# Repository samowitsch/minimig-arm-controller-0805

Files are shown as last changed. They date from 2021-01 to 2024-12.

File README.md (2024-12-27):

# Minimig-ARM-Controller-0805

Rebuild Minimig ARM Controller board using 0805 SMD components.

> ⚠️ IMPORTANT NOTICE! It seems that only the first rev 1 of my Minimig controller is working! See issue #1

## Preface

Thanks to [Dennis van Weeren](https://en.wikipedia.org/wiki/Minimig), Jakub Bednarski and all contributors for the great [Minimig](https://en.wikipedia.org/wiki/Minimig) project! 
_"Never give up, never surrender!"_ **;o)**

## Disclaimer

> Use/build this project/pcb at your own risk. I am a hobbyist and not an professional 
> electrician or pcb designer and not responsive for any damage to your Minimig.
> 
> By the way my version is not as smart and elegant like the original, i am just using 
> 4 layers instead of two ;o)

## Introduction

Me as a late starter to the Minimig project late 2020 wants to build a [Minimig](https://en.wikipedia.org/wiki/Minimig) to get again the Amiga feeling i 
had a couple of years ago where i owned the most models of the [Amiga](https://en.wikipedia.org/wiki/Amiga) family.

First i tried to solder the [ARM controller board](https://www.amigawiki.org/doku.php?id=de:expansion:storage:minimig_arm_controller) needed for the [Minimig](https://en.wikipedia.org/wiki/Minimig). I ment i was good in soldering but screwed up ;o)
Because of this defeat i decided to make a board using 0805 SMD components for easy hand soldering. And my eyes are also not the very best at all ;-)

## What is included in this repository?

* KiCad files
* Gerber files
* [Firmware files](/firmware/Readme.md)

## BOM

This rebuild pcb uses the same designators as the existing ARM controller.
To buy the parts for this board you can use the existing [a1k.org parts list](resources/minimig_arm_v11fix_bestueckung.pdf).
But instead of 0603 components you can use the larger 0805 smd components.

## How to flash the ARM Controller firmware

The needed firmware [you can find here](https://www.a1k.org/forum/index.php?threads/39601/) (requires registration) or in [this repository](/firmware/Readme.md).

### Flash standalone

1. Connect the TEST header pins with a jumper. Then power up the board with 3.3 V connected to the 
   DC pins (double check correct orientation!) for round about 7 - 10 seconds (see picture below). Shutdown the power again. 
   Remove the jumper from TEST header pins. The Atmel AT91SAM7S256 MCU should be now in usb programming mode.

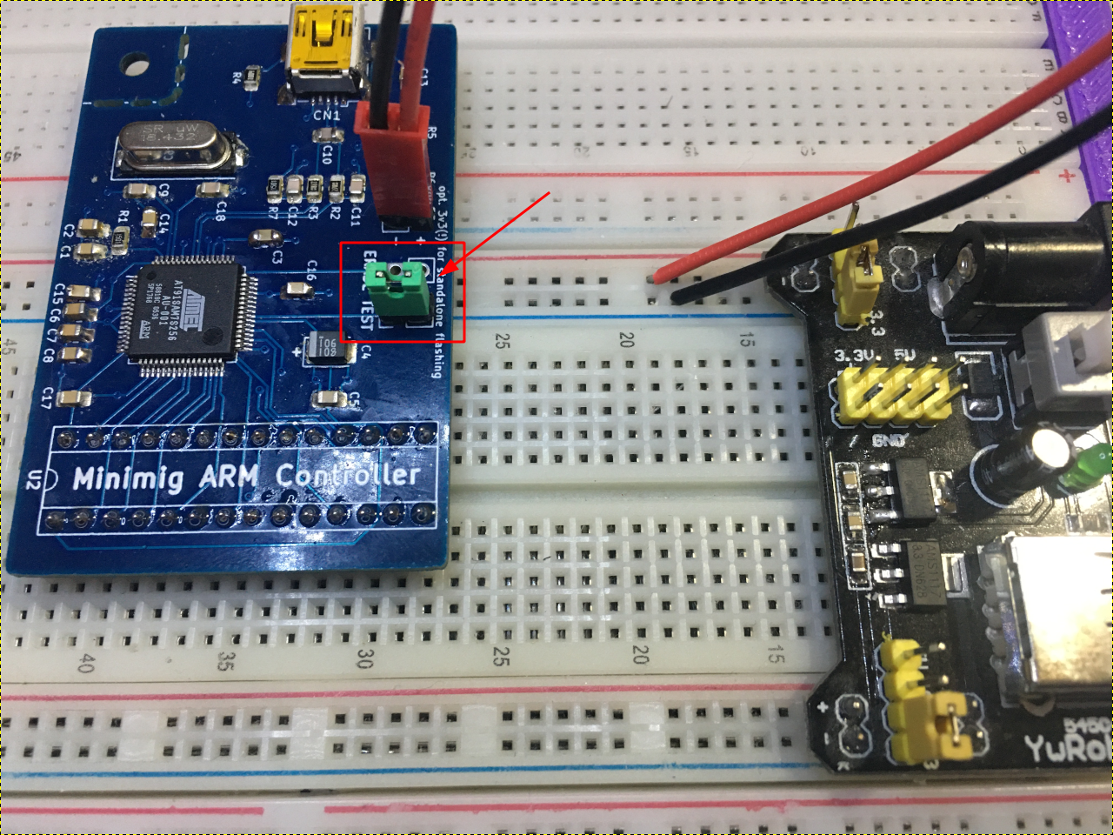
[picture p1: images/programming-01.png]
programming-01


2. Now connect the ARM controller with the USB cable to your pc. And power up the board again.

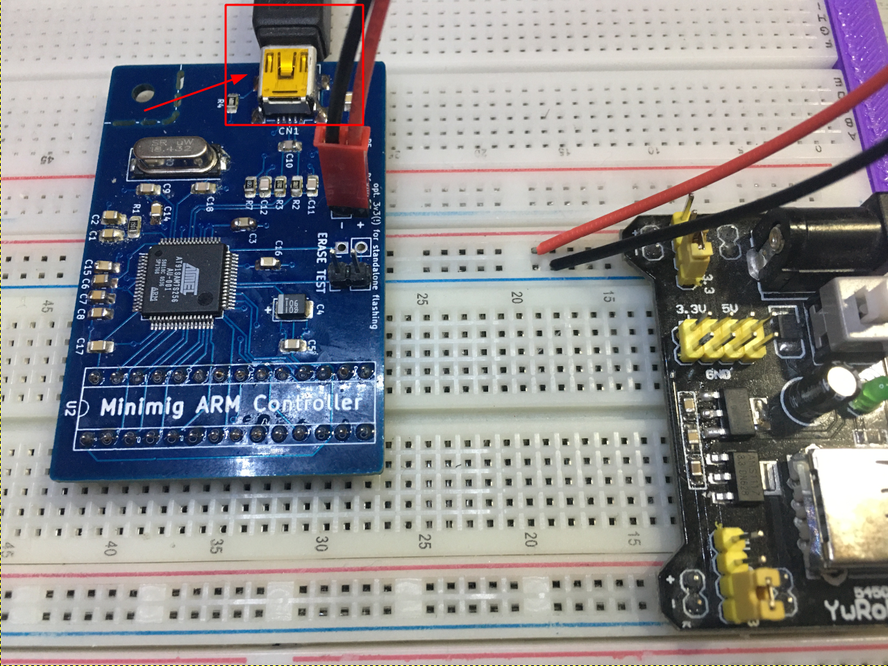
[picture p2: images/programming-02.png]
programming-02


3. For example under Ubuntu you should see now a usb device **/dev/ttyACM0**. For 
   Ubuntu you need the [SAM-BA CDC 2.18](https://www.microchip.com/en-us/development-tool/SAM-BA-In-system-Programmer) ([Download](https://ww1.microchip.com/downloads/en/DeviceDoc/SAM-BA+v2.18+for+Linux.zip)) utility (maybe a newer version is working too).

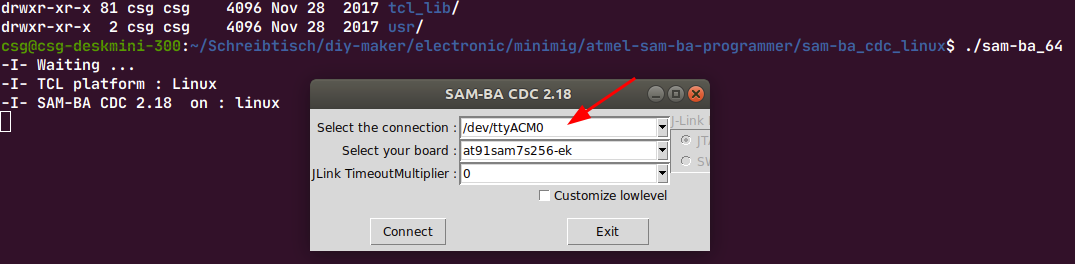
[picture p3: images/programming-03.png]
programming-03


4. When connected choose the bin firmware file and press "Send File".

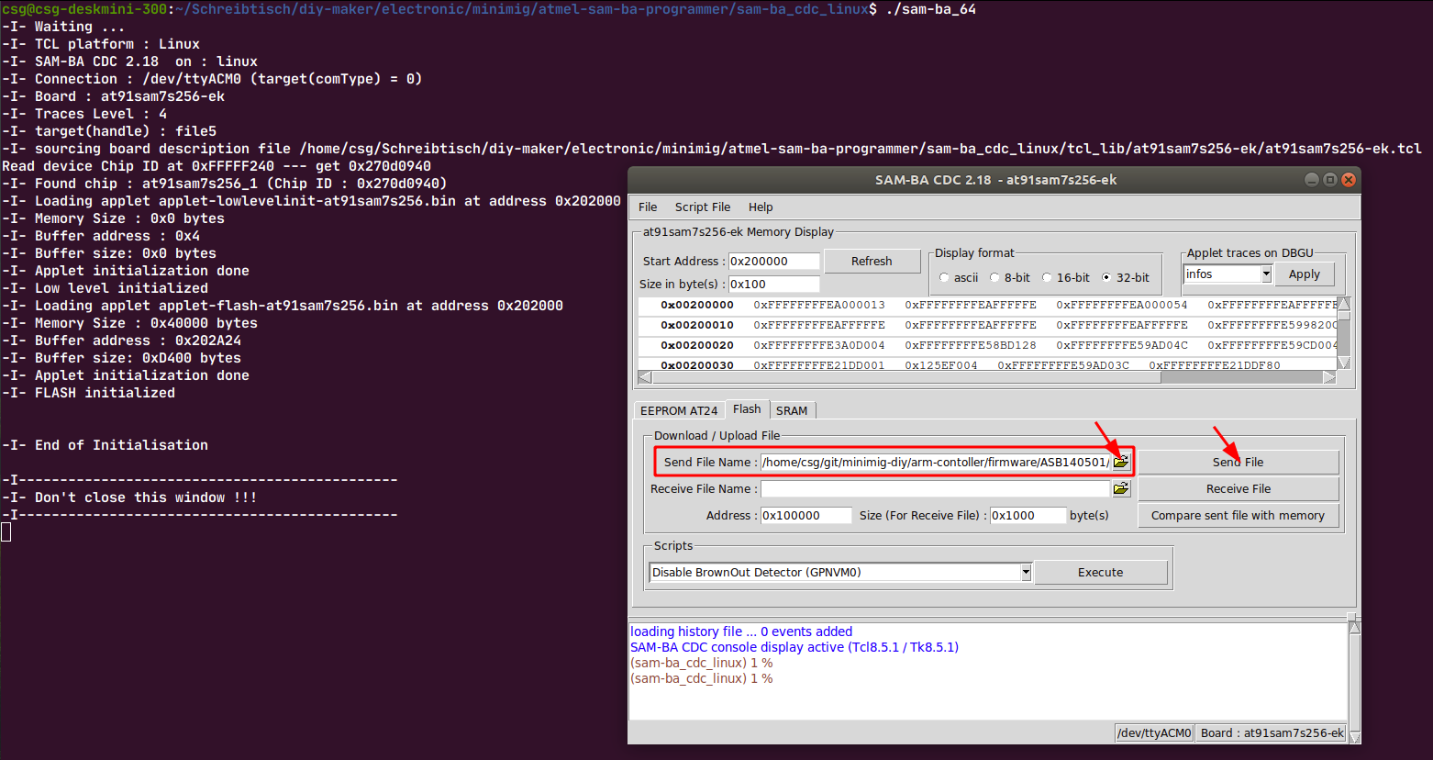
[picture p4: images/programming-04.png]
programming-04


5. In next dialoges for unlock/lock regions you can press "Ja"/"Yes" two times.

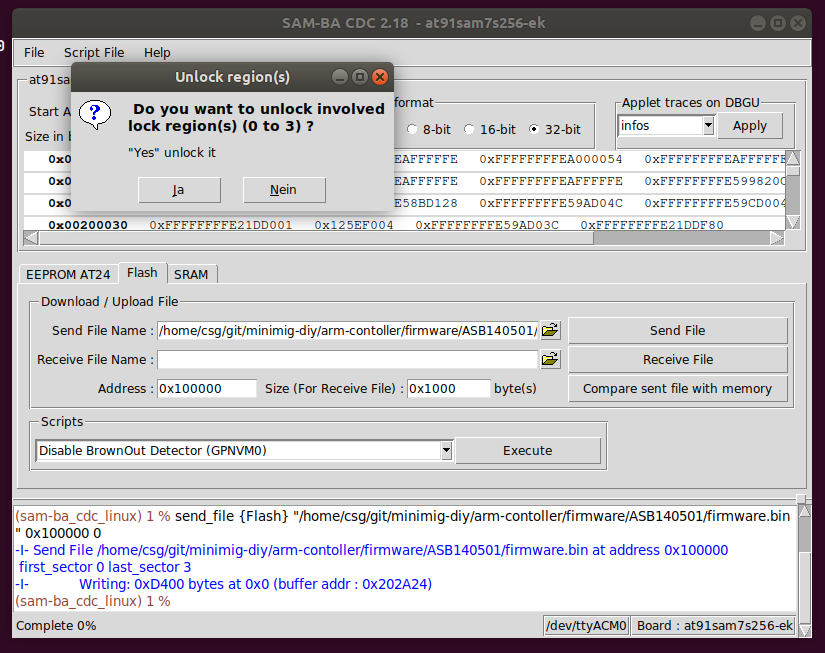
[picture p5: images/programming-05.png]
programming-05

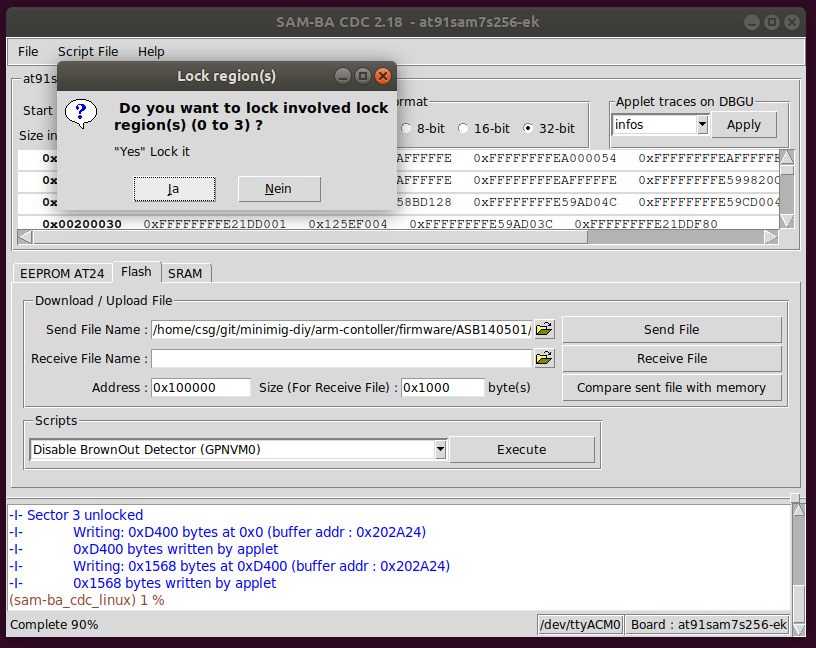
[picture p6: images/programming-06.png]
programming-06


6. At the end you can verify if the flashing process where 
   successfully on pressing "Compare sent file with memory"

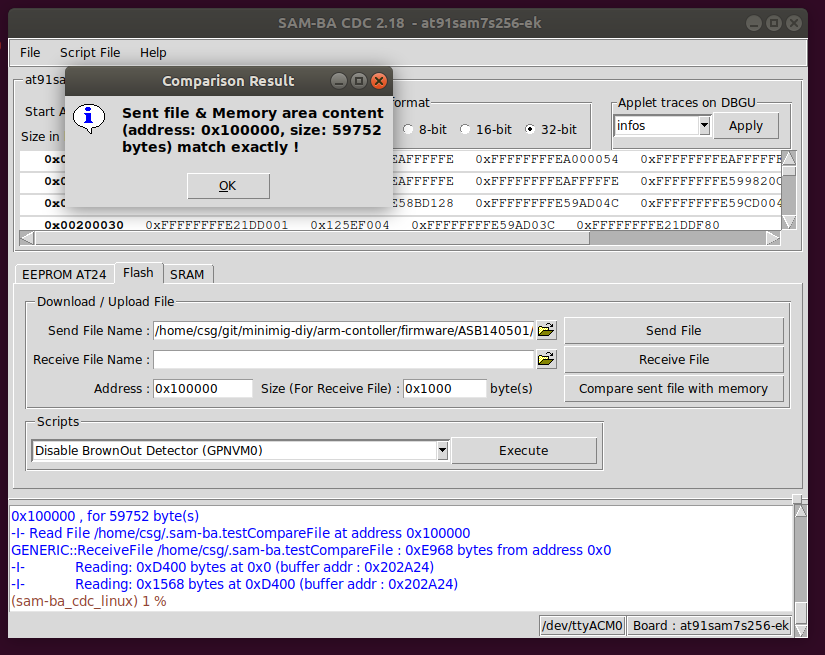
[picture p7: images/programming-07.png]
programming-07


### Flash connected to Minimig

Should work in the same way as described above with the difference that the 
board is connected to the Minimig and get its power from there.

## Mounted ARM controller

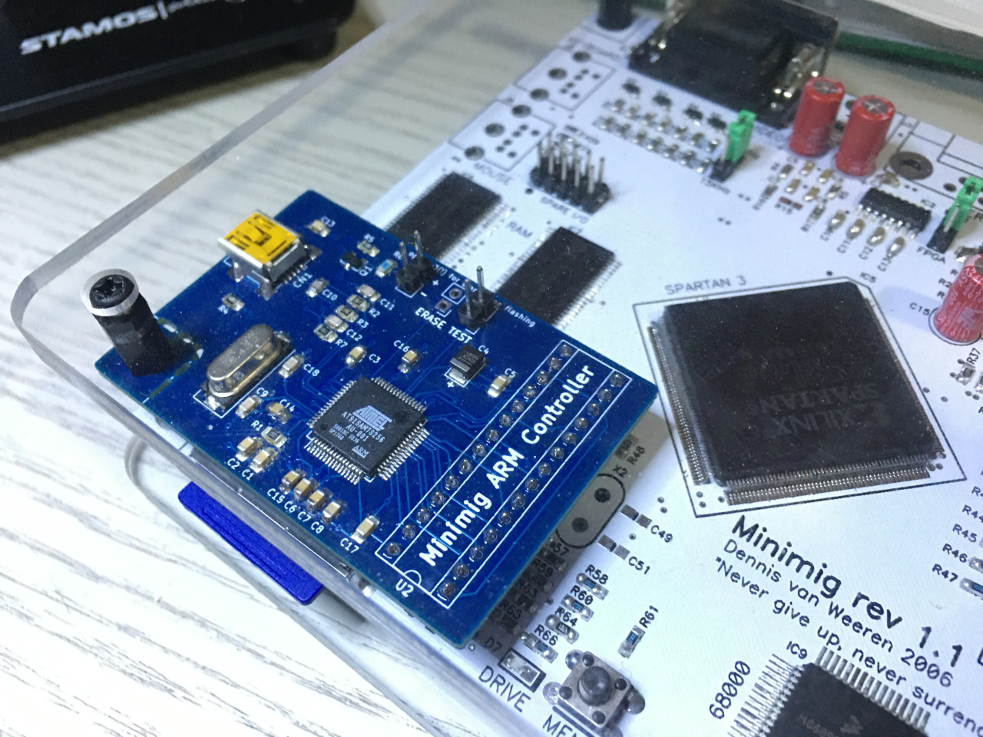
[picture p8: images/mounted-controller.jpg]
mounted-controller


## Running Minimig v1.1 with my version

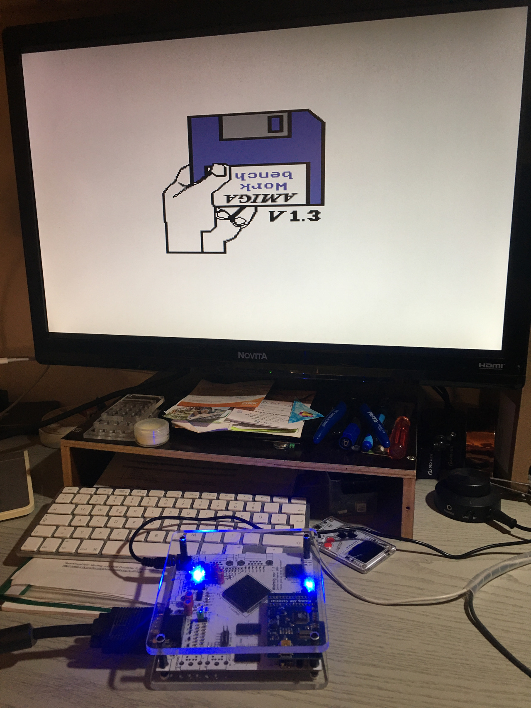
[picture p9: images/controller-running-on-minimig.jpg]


## PCB Layers

Layer Nr | Comment
--- | ---
1 | Signal
2 | +1V8 plane VDDCORE
3 | +3V3 plane VDDIN
4 | GND plane/Signal

## Comparison between versions

0805 rev1.0.3 | 0805 rev1.0.2 | 0805 rev1 | original 0603 version
--- | --- | --- | ---
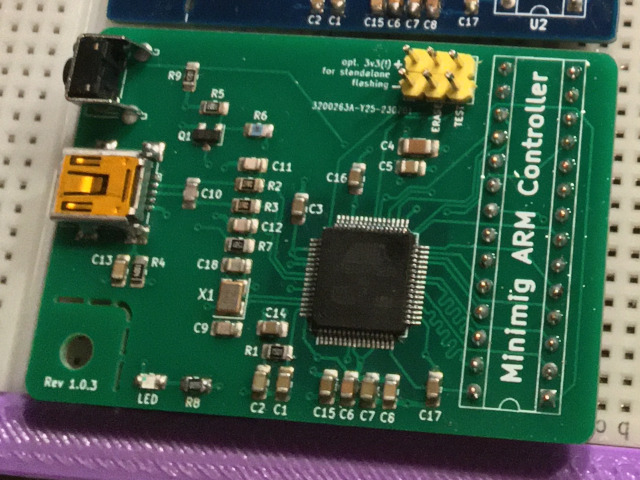
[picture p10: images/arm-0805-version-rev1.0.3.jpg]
arm-0805-version
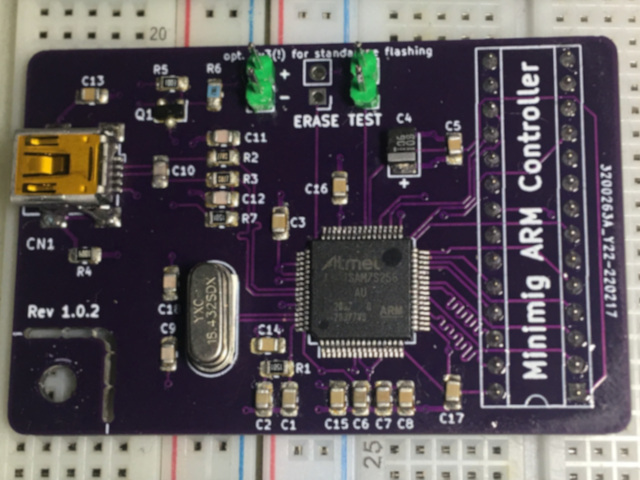
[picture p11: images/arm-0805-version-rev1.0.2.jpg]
arm-0805-version
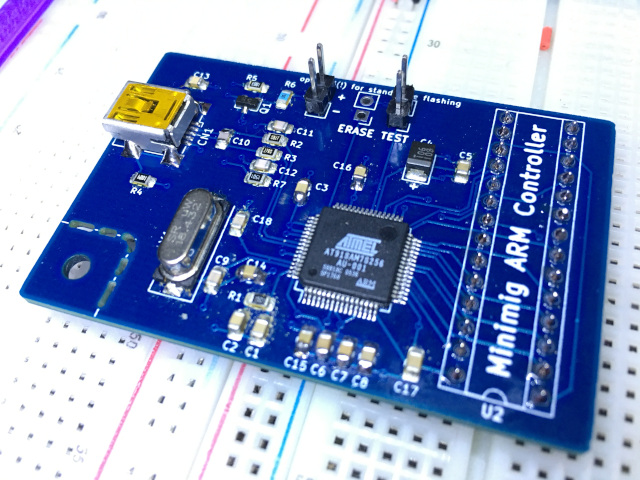
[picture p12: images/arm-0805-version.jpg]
arm-0805-version
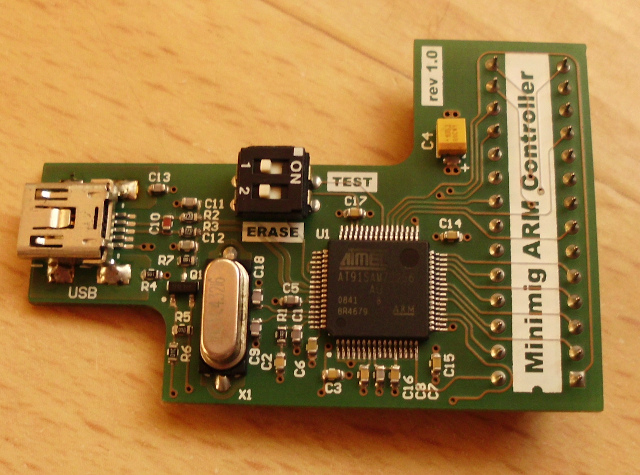
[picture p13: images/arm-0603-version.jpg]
arm-0603-version
 |  |                | 
no stable | not stable | stable(?) |
changes: reset button, power led, smd resonator | changes: dont know anymore ;o) |  | What a beauty of a pcb design of Jakub!
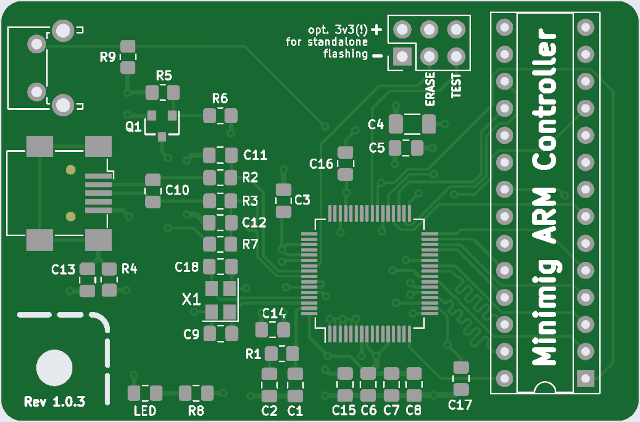
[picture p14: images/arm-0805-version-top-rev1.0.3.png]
arm-0805-version-top
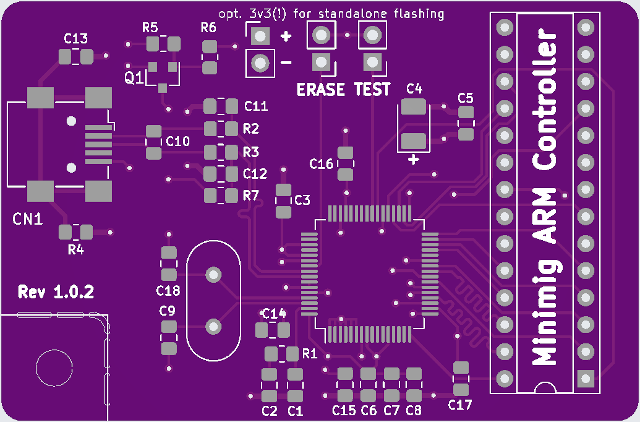
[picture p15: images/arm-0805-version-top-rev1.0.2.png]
arm-0805-version-top
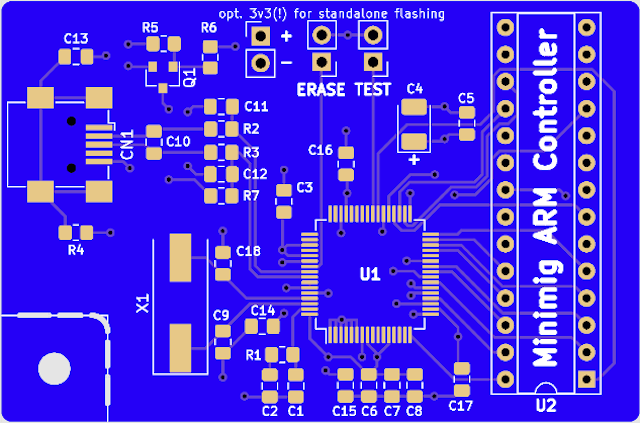
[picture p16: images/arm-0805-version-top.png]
arm-0805-version-top
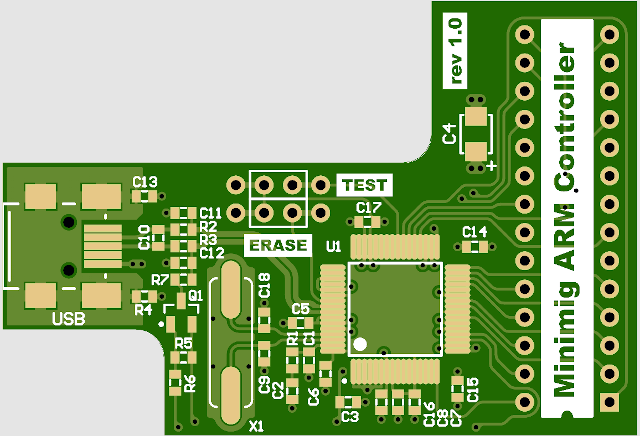
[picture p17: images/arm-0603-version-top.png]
arm-0603-version-top
 |  |  | 
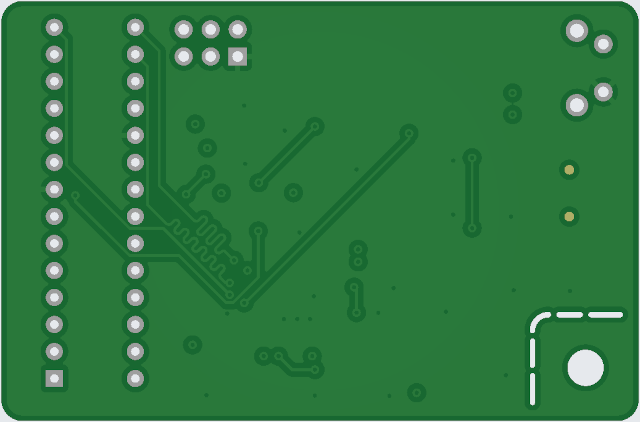
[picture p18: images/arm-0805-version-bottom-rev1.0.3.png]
arm-0805-version-bottom
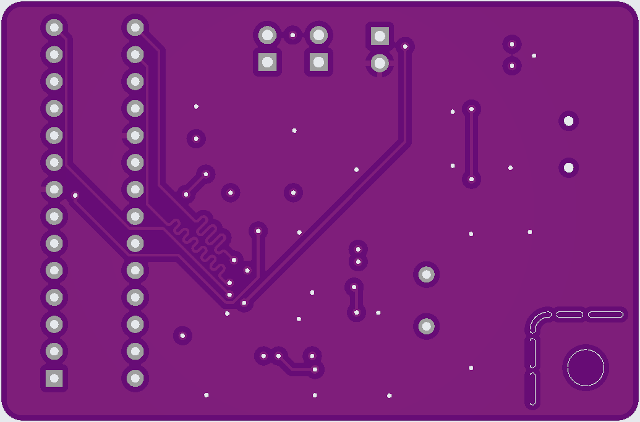
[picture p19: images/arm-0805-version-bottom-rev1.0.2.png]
arm-0805-version-bottom
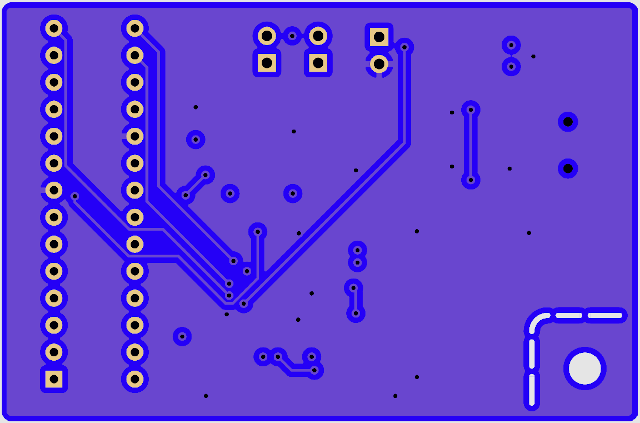
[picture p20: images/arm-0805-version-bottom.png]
arm-0805-version-bottom
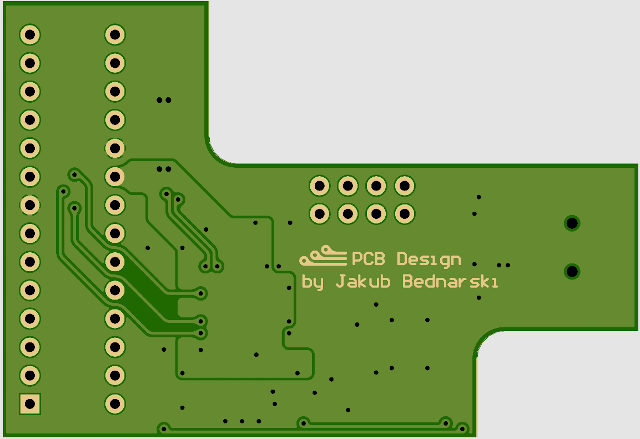
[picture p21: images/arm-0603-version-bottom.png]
arm-0603-version-bottom
 |  |  | 

## Resources and links

* [Original Minimig page](https://www.techtravels.org/wp-content/uploads/pefiles/minimig/weeren001/minimig.html)
* [Minimig on a1k.org](https://www.a1k.org/forum/index.php?forums/53/)
* [Minimig on amigawiki.org](https://www.amigawiki.org/doku.php?id=de:models:minimig)
* [Minimig on Wikipedia](https://en.wikipedia.org/wiki/Minimig)
* [Minimig on Illuwatar Design](http://www.illuwatar.se/)
* [Make: Poor man's Minimig ARM Controller](https://sweetlilmre.blogspot.com/2013/05/make-poor-mans-minimig-arm-controller.html)
* [An FPPGA based Amiga – The Minimig](https://theretrohacker.com/2022/12/20/an-fppga-based-amiga-the-minimig/)
* [cristianoag/minimig](https://github.com/cristianoag/minimig)
* [wiretap-retro/MigStorm-ITX](https://github.com/wiretap-retro/MigStorm-ITX)
* [minimig.ca](https://www.minimig.ca/index.php/software/)
* [0805 Minimig Arm Controller on MigStorm ITX](https://youtu.be/l10HLR_F88E?si=PKMIdRAqAoQ9IPDd&t=572)

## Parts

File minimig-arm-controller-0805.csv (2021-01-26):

Reference | Quantity | Value | Footprint | Datasheet
C10 | 1 | 33p | Capacitor_SMD:C_0805_2012Metric_Pad1.18x1.45mm_HandSolder | ~
C11 C12 | 2 | 15p | Capacitor_SMD:C_0805_2012Metric_Pad1.18x1.45mm_HandSolder | ~
C1 C5 C8 C13 | 4 | 1n | Capacitor_SMD:C_0805_2012Metric_Pad1.18x1.45mm_HandSolder | ~
C9 C18 | 2 | 10p | Capacitor_SMD:C_0805_2012Metric_Pad1.18x1.45mm_HandSolder | ~
C2 | 1 | 10n | Capacitor_SMD:C_0805_2012Metric_Pad1.18x1.45mm_HandSolder | ~
C3 C14 C15 C16 C17 | 5 | 100n | Capacitor_SMD:C_0805_2012Metric_Pad1.18x1.45mm_HandSolder | ~
C4 | 1 | 10u/16V | Capacitor_Tantalum_SMD:CP_EIA-3528-21_Kemet-B_Pad1.50x2.35mm_HandSolder | ~
C6 C7 | 2 | 1u | Capacitor_SMD:C_0805_2012Metric_Pad1.18x1.45mm_HandSolder | ~
CN1 | 1 | USB_B_Mini | Connector_USB:USB_Mini-B_Wuerth_65100516121_Horizontal | ~
JP1 J1 JP2 | 3 | Conn_01x02_Male | Connector_PinHeader_2.54mm:PinHeader_1x02_P2.54mm_Vertical | ~
Q1 | 1 | BC807 | Package_TO_SOT_SMD:SOT-23 | https://www.onsemi.com/pub/Collateral/BC808-D.pdf
R2 R3 | 2 | 27R | Resistor_SMD:R_0805_2012Metric_Pad1.20x1.40mm_HandSolder | ~
R4 | 1 | 1M | Resistor_SMD:R_0805_2012Metric_Pad1.20x1.40mm_HandSolder | ~
R5 | 1 | 100K | Resistor_SMD:R_0805_2012Metric_Pad1.20x1.40mm_HandSolder | ~
R6 | 1 | 10K | Resistor_SMD:R_0805_2012Metric_Pad1.20x1.40mm_HandSolder | ~
R1 R7 | 2 | 1K5 | Resistor_SMD:R_0805_2012Metric_Pad1.20x1.40mm_HandSolder | ~
U1 | 1 | AT91SAM7S256 | Package_QFP:LQFP-64_10x10mm_P0.5mm
U2 | 1 | PIC_PIN_HEADER | Package_DIP:DIP-28_W7.62mm_Socket
X1 | 1 | 18.342MHz | Crystal:Crystal_SMD_HC49-SD | ~

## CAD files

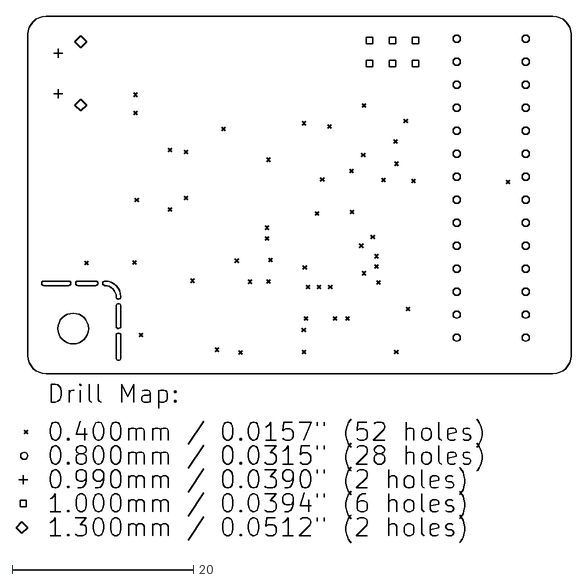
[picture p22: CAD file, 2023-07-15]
gerber/minimig-arm-controller-0805-PTH-drl_map.dxf
61.3 x 58.2

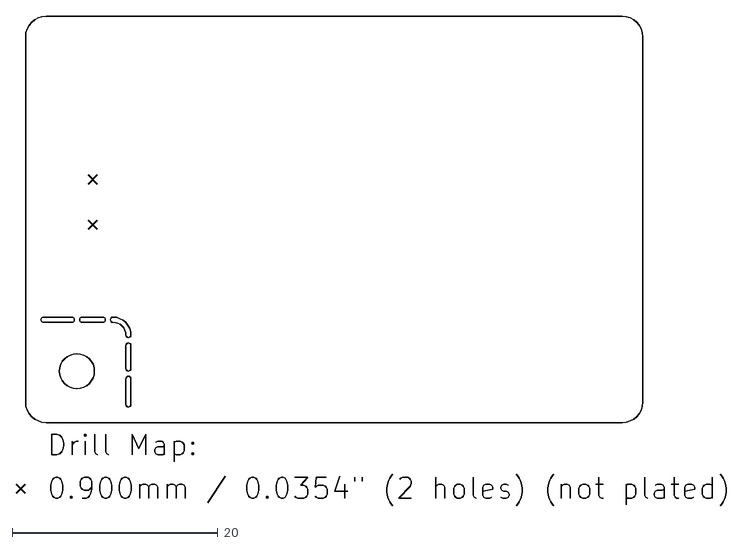
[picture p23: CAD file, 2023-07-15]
gerber/minimig-arm-controller-0805-NPTH-drl_map.dxf
69.0 x 47.6

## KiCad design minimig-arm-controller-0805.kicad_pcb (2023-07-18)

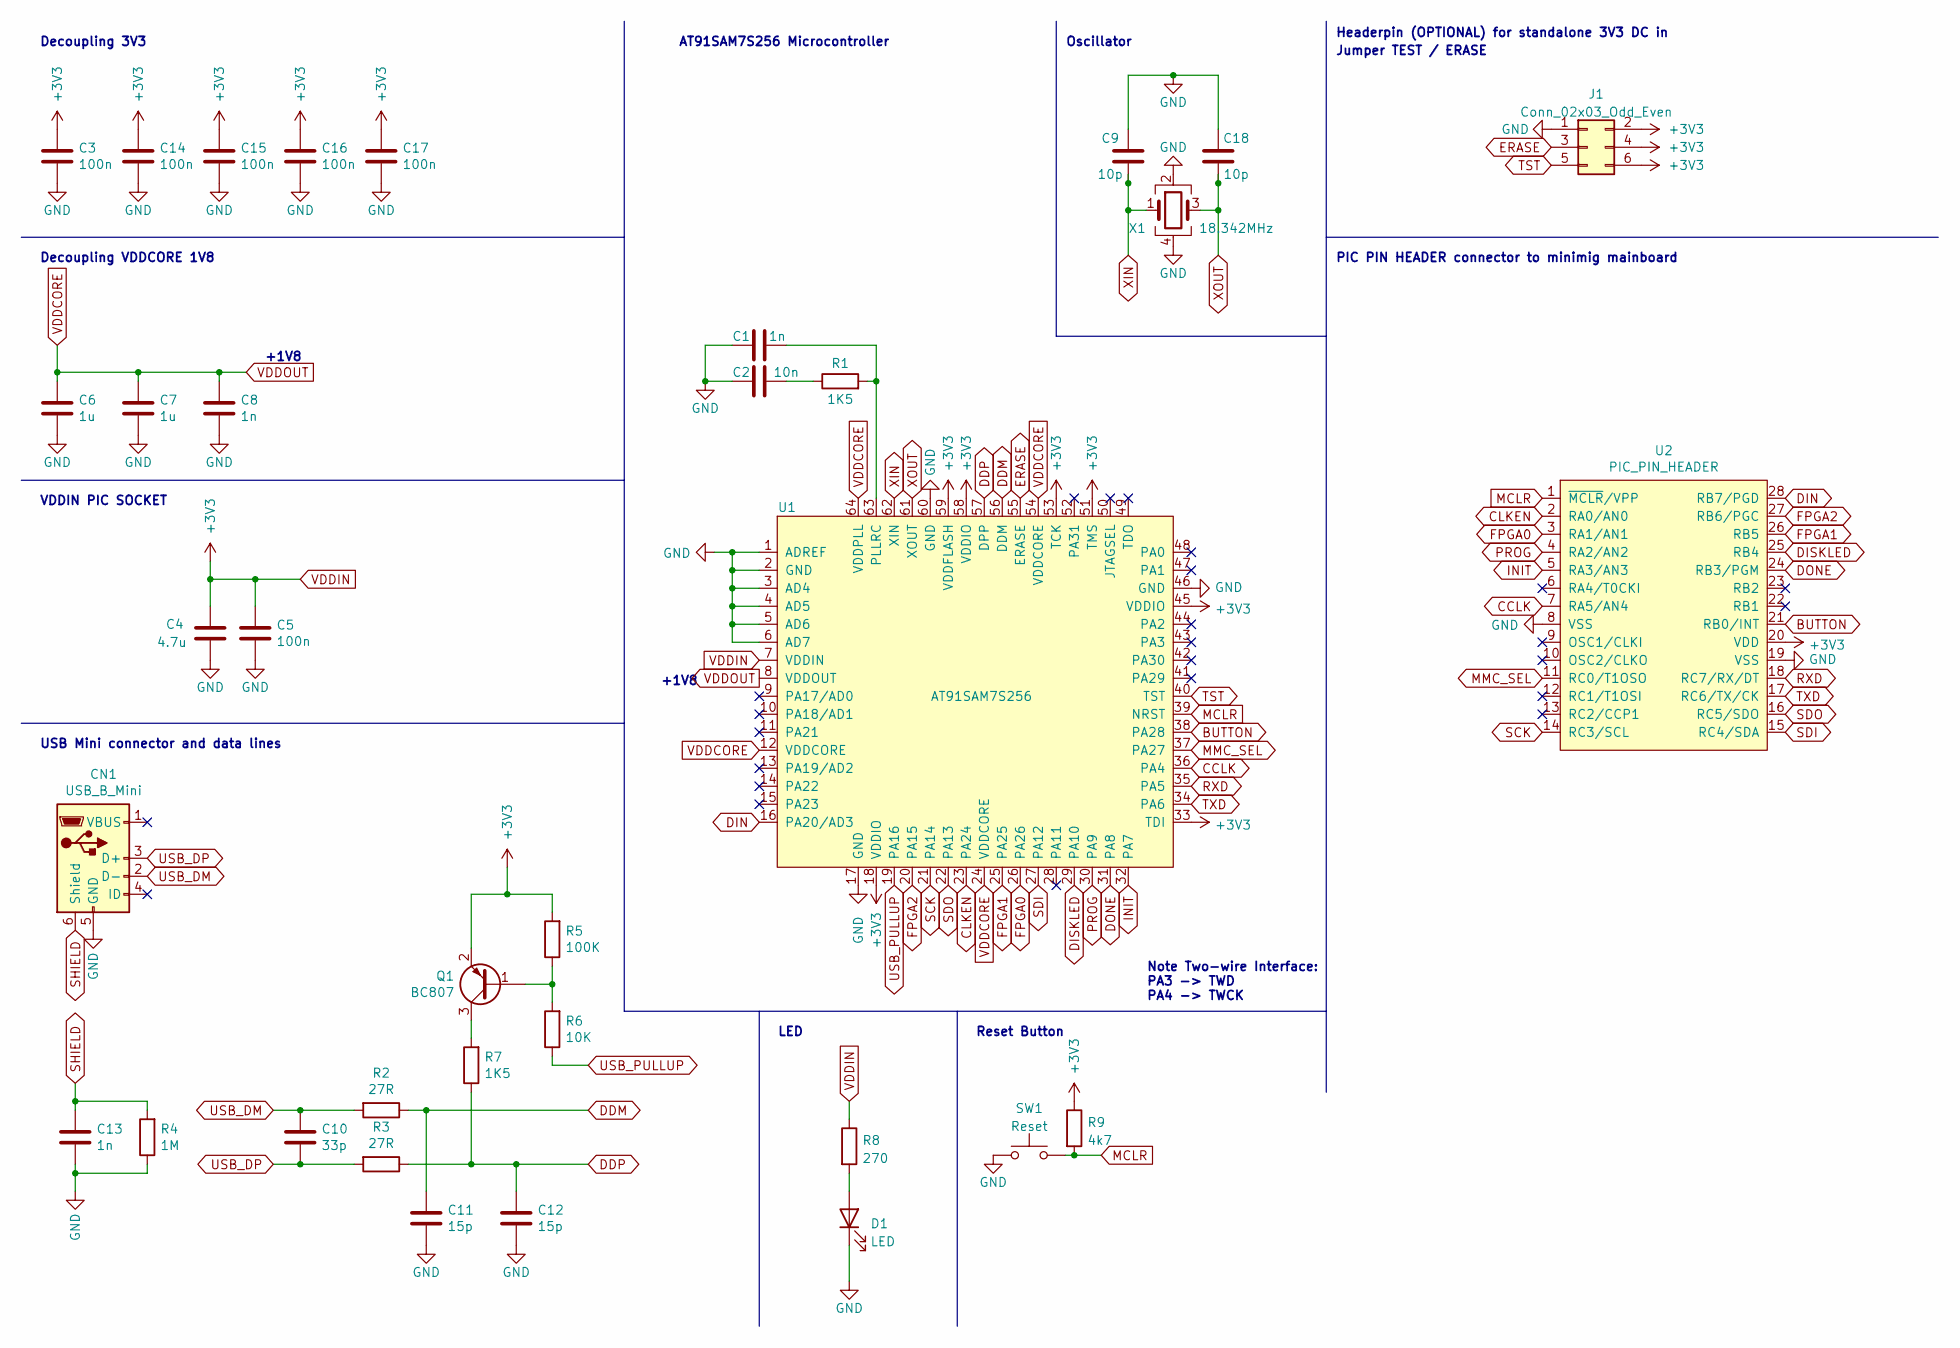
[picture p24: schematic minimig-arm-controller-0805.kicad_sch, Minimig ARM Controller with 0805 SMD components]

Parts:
C1, C8, C13: 1n; C_0805_2012Metric_Pad1.18x1.45mm_HandSolder
C2: 10n; C_0805_2012Metric_Pad1.18x1.45mm_HandSolder
C3, C5, C14, C15, C16, C17: 100n; C_0805_2012Metric_Pad1.18x1.45mm_HandSolder
C4: 4.7u; C_1206_3216Metric_Pad1.33x1.80mm_HandSolder
C6, C7: 1u; C_0805_2012Metric_Pad1.18x1.45mm_HandSolder
C9, C18: 10p; C_0805_2012Metric_Pad1.18x1.45mm_HandSolder
C10: 33p; C_0805_2012Metric_Pad1.18x1.45mm_HandSolder
C11, C12: 15p; C_0805_2012Metric_Pad1.18x1.45mm_HandSolder
CN1: USB_B_Mini; USB_Mini-B_Wuerth_65100516121_Horizontal
D1: LED; C_0805_2012Metric_Pad1.18x1.45mm_HandSolder
J1: Conn_02x03_Odd_Even; PinHeader_2x03_P2.54mm_Vertical
Q1: BC807; SOT-23
R1, R7: 1K5; R_0805_2012Metric_Pad1.20x1.40mm_HandSolder
R2, R3: 27R; R_0805_2012Metric_Pad1.20x1.40mm_HandSolder
R4: 1M; R_0805_2012Metric_Pad1.20x1.40mm_HandSolder
R5: 100K; R_0805_2012Metric_Pad1.20x1.40mm_HandSolder
R6: 10K; R_0805_2012Metric_Pad1.20x1.40mm_HandSolder
R8: 270; C_0805_2012Metric_Pad1.18x1.45mm_HandSolder
R9: 4k7; R_0805_2012Metric_Pad1.20x1.40mm_HandSolder
SW1: Reset; SW_Tactile_SPST_Angled_PTS645Vx39-2LFS
U1: AT91SAM7S256; LQFP-64_10x10mm_P0.5mm
U2: PIC_PIN_HEADER; DIP-28_W7.62mm_Socket
X1: 18.342MHz; Crystal_SMD_3225-4Pin_3.2x2.5mm

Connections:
BUTTON: U1.38 (PA28), U2.21 (RB0/INT)
CCLK: U1.36 (PA4), U2.7 (RA5/AN4)
CLKEN: U1.23 (PA24), U2.2 (RA0/AN0)
DDM: C11.1, R2.1, U1.56 (DDM)
DDP: C12.1, R3.1, R7.1, U1.57 (DPP)
DIN: U1.16 (PA20/AD3), U2.28 (RB7/PGD)
DISKLED: U1.29 (PA10), U2.25 (RB4)
DONE: U1.31 (PA8), U2.24 (RB3/PGM)
ERASE: J1.3, U1.55 (ERASE)
FPGA0: U1.26 (PA26), U2.3 (RA1/AN1)
FPGA1: U1.25 (PA25), U2.26 (RB5)
FPGA2: U1.20 (PA15), U2.27 (RB6/PGC)
GND: C1.2, C2.2, C3.2, C4.2, C5.2, C6.2, C7.2, C8.2, C9.2, C11.2, C12.2, C13.2, C14.2, C15.2, C16.2, C17.2, C18.2, CN1.5 (GND), D1.1 (K), J1.1, R4.1, SW1.1, U1.1 (ADREF), U1.2 (GND), U1.3 (AD4), U1.4 (AD5), U1.5 (AD6), U1.6 (AD7), U1.17 (GND), U1.46 (GND), U1.60 (GND), U2.8 (VSS), U2.19 (VSS), X1.2, X1.4
INIT: U1.32 (PA7), U2.5 (RA3/AN3)
MCLR: R9.2, SW1.2, U1.39 (NRST), U2.1 (~MCLR/VPP)
MMC_SEL: U1.37 (PA27), U2.11 (RC0/T1OSO)
unnamed: C1.1, R1.2, U1.63 (PLLRC)
unnamed: C2.1, R1.1
unnamed: D1.2 (A), R8.2
unnamed: Q1.1 (B), R5.1, R6.2
unnamed: Q1.3 (C), R7.2
PROG: U1.30 (PA9), U2.4 (RA2/AN2)
RXD: U1.35 (PA5), U2.18 (RC7/RX/DT)
SCK: U1.21 (PA14), U2.14 (RC3/SCL)
SDI: U1.27 (PA12), U2.15 (RC4/SDA)
SDO: U1.22 (PA13), U2.16 (RC5/SDO)
SHIELD: C13.1, CN1.6 (Shield), R4.2
TST: J1.5, U1.40 (TST)
TXD: U1.34 (PA6), U2.17 (RC6/TX/CK)
USB_DM: C10.1, CN1.2 (D-), R2.2
USB_DP: C10.2, CN1.3 (D+), R3.2
USB_PULLUP: R6.1, U1.19 (PA16)
VDDCORE: C6.1, C7.1, C8.1, U1.8 (VDDOUT), U1.12 (VDDCORE), U1.24 (VDDCORE), U1.54 (VDDCORE), U1.64 (VDDPLL)
VDDIN: C3.1, C4.1, C5.1, C14.1, C15.1, C16.1, C17.1, J1.2, J1.4, J1.6, Q1.2 (E), R5.2, R8.1, R9.1, U1.7 (VDDIN), U1.18 (VDDIO), U1.33 (TDI), U1.45 (VDDIO), U1.51 (TMS), U1.53 (TCK), U1.58 (VDDIO), U1.59 (VDDFLASH), U2.20 (VDD)
XIN: C9.1, U1.62 (XIN), X1.1
XOUT: C18.1, U1.61 (XOUT), X1.3

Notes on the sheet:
Decoupling VDDCORE 1V8
LED
USB Mini connector and data lines
Headerpin (OPTIONAL) for standalone 3V3 DC in
VDDIN PIC SOCKET
PIC PIN HEADER connector to minimig mainboard
+1V8
Oscillator
Jumper TEST / ERASE
Decoupling 3V3
Note Two-wire Interface: PA3 -> TWD PA4 -> TWCK
Reset Button
AT91SAM7S256 Microcontroller

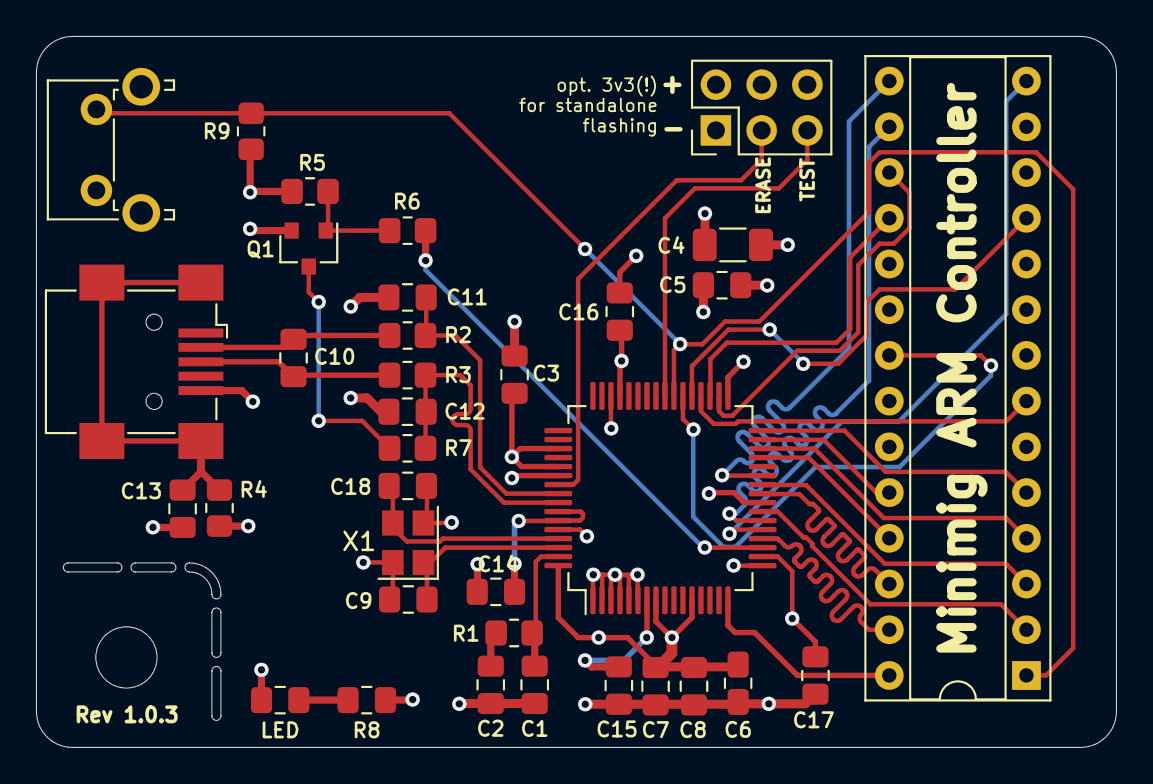
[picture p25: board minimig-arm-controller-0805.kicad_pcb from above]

Board: 4 copper layers, 60.0 x 39.5 mm, 35 parts (0 on the bottom side), 36 nets.

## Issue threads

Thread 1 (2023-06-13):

has anyone done the test?

juanpc2018, 2023-06-13:
since this mod is only  for the original minimig v1.3
https://www.techtravels.org/wp-content/uploads/pefiles/minimig/weeren001/home.html
https://www.minimig.ca/index.php/2021/07/19/minimig-v1-3/

has anyone tested:
Minimig 1.3 + ARM
vs.
New Minimig https://www.minimig.ca/
vs.
MIST https://lotharek.pl/productdetail.php?id=45
vs.
MISTer ?

samowitsch, 2023-06-19:
That's not really a issue. Rather a performance question for a amiga retro forum.
Personally, i only own a Minimig V1.1 with ARM controller and have no comparison to other solutions.

Closed 2023-06-19.

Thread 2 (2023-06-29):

ℹ️ Arm controller not working properly ? 😤

samowitsch, 2023-06-29:
Brief history. Back in 2020, at the beginning of soldering my miming, I failed to solder Jacub's 0603 arm controller.
This is the reason why this repo exists. It is lets say a replica with 0805 components that i made.

I am just soldering again some Arm Controllers for the Minimig and this is driving me nuts. All new soldered Arm controllers are not working propery. Each Rev i made. Only the first two blue rev 1 versions that i made in the past are working.

And all the successors in blue (even the "old" blue rev1 pcb too), green and purple do not work reliably.
Minimig is starting up and then fails randomly with a bluescreen. The latest point is trying to upload the kickstart into memory.

I don't know exactly what the problem is. I am not sure. Maybe i have an issue on the pcb or even faulty components or china clones of the Atmel AT91SAM7S256 MCU? Who knows...

The blue at the bottom is working.
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

samowitsch, 2023-07-15:
The rev1.0.3 has the same behaviour a the others before 🥴

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

It stucks on the blue bootscreen. Mostly it hangs when he tries to upload the kickstart into ram.

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
The output has some jitter (not visible on photo).

Maybe there is a power issue. Or my bad pcb layout is the reason. Or in worst case with the mcu itself. My running versions are  all labeled with **AU-001** ? 🤔

samowitsch, 2025-01-01:
Surprisingly i found a YT video with a working rev 1.0.2 of my minimig arm controller pcb 🤗
Then some components that i have used is causing my problems 😡

https://youtu.be/l10HLR_F88E?si=VD0iGX84BHG4OUzv&t=526

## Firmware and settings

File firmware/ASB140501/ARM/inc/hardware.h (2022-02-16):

#define MCLK 48000000
#define FWS 1 // Flash wait states

#define DISKLED    AT91C_PIO_PA10
#define MMC_CLKEN  AT91C_PIO_PA24
#define MMC_SEL    AT91C_PIO_PA27
#define DIN AT91C_PIO_PA20
#define CCLK AT91C_PIO_PA4
#define PROG_B AT91C_PIO_PA9
#define INIT_B AT91C_PIO_PA7
#define DONE AT91C_PIO_PA8
#define FPGA0 AT91C_PIO_PA26
#define FPGA1 AT91C_PIO_PA25
#define FPGA2 AT91C_PIO_PA15
#define BUTTON AT91C_PIO_PA28

#define DISKLED_ON *AT91C_PIOA_SODR = DISKLED;
#define DISKLED_OFF *AT91C_PIOA_CODR = DISKLED;
// #define RAMFUNC   __attribute__ ((section(".ramsection")))
#define RAMFUNC __attribute__ ((section (".text.fastcode")))
void init_hardware(void);
void USART_Init(unsigned long baudrate);
void USART_Write(unsigned char c);
void USART_Putc(void* p, char c);
RAMFUNC void SPI_Init(void);
RAMFUNC unsigned char SPI(unsigned char outByte);
RAMFUNC void SPI_Wait4XferEnd(void);
RAMFUNC void EnableCard(void);
RAMFUNC void DisableCard(void);
void EnableFpga(void);
void DisableFpga(void);
void EnableOsd(void);
void DisableOsd(void);
unsigned long CheckButton(void);
void Timer_Init(void);
unsigned long GetTimer(unsigned long offset);
unsigned long CheckTimer(unsigned long t);
void WaitTimer(unsigned long time);

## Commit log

2021-01-26 add KiCad project files
    [minimig-arm-controller-0805-B_Cu.gbr, minimig-arm-controller-0805-B_Mask.gbr, minimig-arm-controller-0805-B_Paste.gbr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]
2021-01-27 added original ARM Controller files
2021-02-10 add text info to schematic about TWI(I2C) pins
    [minimig-arm-controller-0805.sch]
2021-05-22 use handsoldering footprint for HC49-SD crystal
    [minimig-arm-controller-0805-B_Cu.gbr, minimig-arm-controller-0805-B_Mask.gbr, minimig-arm-controller-0805-B_Paste.gbr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]
2022-02-16 rev1.0.2: some minor changes. change HC49 to THT
    [minimig-arm-controller-0805-B_Cu.gbr, minimig-arm-controller-0805-B_Mask.gbr, minimig-arm-controller-0805-B_Paste.gbr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]
2022-02-16 remove and gitignore kicad backups
2022-02-17 rev1.0.3 reroute some stuff
    [minimig-arm-controller-0805-B_Cu.gbr, minimig-arm-controller-0805-B_Mask.gbr, minimig-arm-controller-0805-B_Paste.gbr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]
2023-06-23 added warning/notive about later pcb revisions that are not working. Dont know why at the moment ;o(
2023-07-08 add gcc-arm-none-eabi-4_8-2014q1-20140314-linux.tar.bz2, ar, and 4479 more files...
2023-07-08 change path in makefile for gcc-arm-none-eabi-4_8-2014q1
2023-07-15 latest pcb changes
    [minimig-arm-controller-0805-B_Cu.gbr, minimig-arm-controller-0805-B_Mask.gbr, minimig-arm-controller-0805-B_Paste.gbr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]
2023-07-15 latest rev. fix detached head and merge conflict.
    [minimig-arm-controller-0805.kicad_pcb, minimig-arm-controller-0805.kicad_sch]
2023-07-18 fix label
    [minimig-arm-controller-0805.kicad_sch]
2023-07-18 small fix after DRC
    [minimig-arm-controller-0805.kicad_pcb]
